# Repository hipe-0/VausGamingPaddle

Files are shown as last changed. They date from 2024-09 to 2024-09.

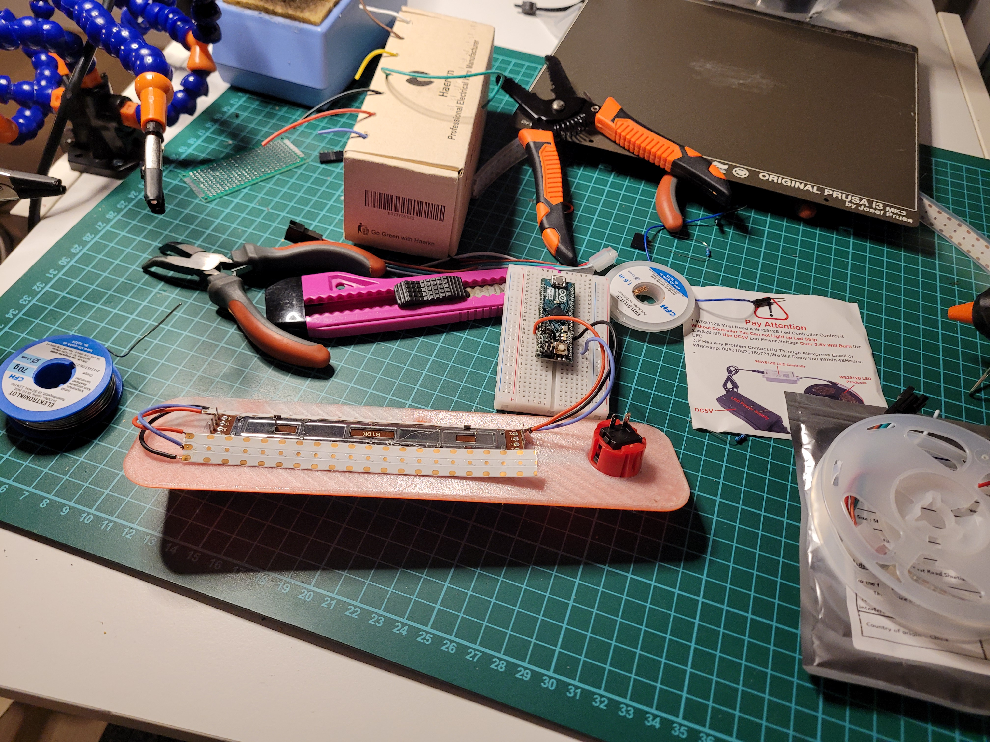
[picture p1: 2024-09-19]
20240102_201649.jpg

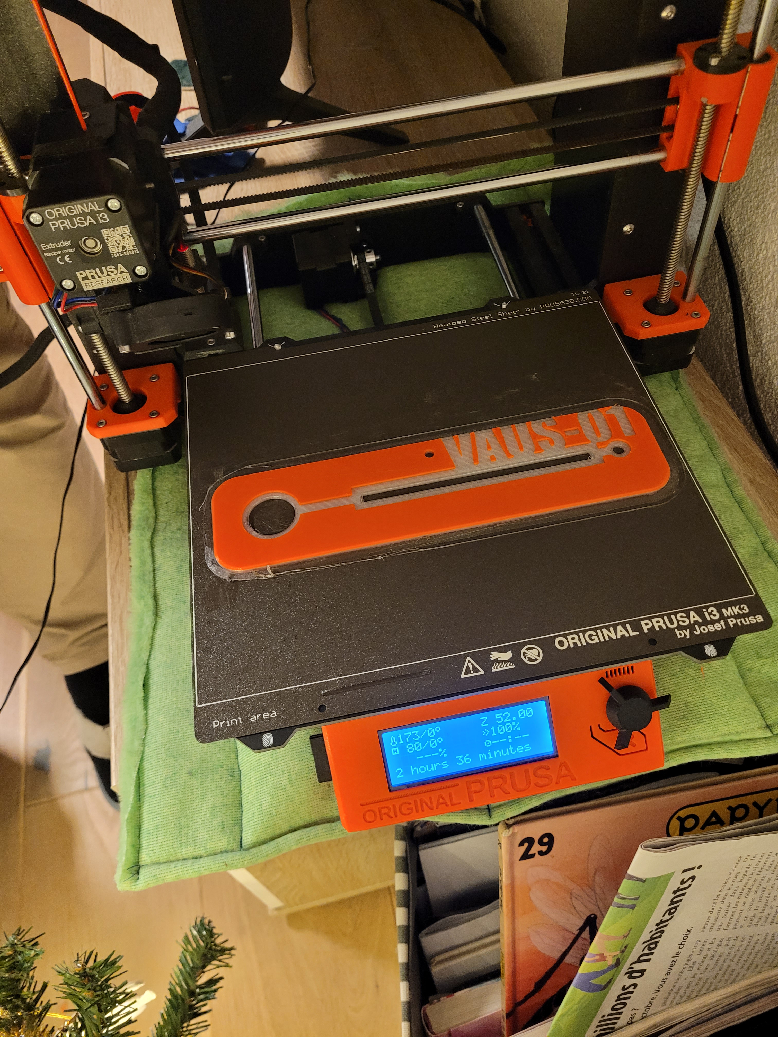
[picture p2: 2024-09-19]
20240102_172037.jpg

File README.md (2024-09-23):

# VausGamingPaddle

I created a 3D printed, open sourced, arduino based, "Arkanoid"-inspired game paddle for playing Arkanoid 1 or 2 games realistically.



https://github.com/user-attachments/assets/acdfcfb8-230b-40b3-95ee-57034bec4c22

Also works with other "breakout" inspired ball game that accept USB mouse as input.

Reference:
https://fr.wikipedia.org/wiki/Arkanoid

# Game controller description
- low, near zero latency
- USB A to usb Micro cable required
- compatibility with PC emulators or consoles
- The device emulates a mouse with only X direction
- 1 game button (for the Arkanoid game it is used as fire button)
- Main sensor bar is a large linear potentiometer, like the ones found on DJ mixer devices
- Paddle movements are accompanied by led effect when moving and firing
- Handles the left and right corners by moving the mouse faster
- Some mouse acceleration is added based on mouse speed, to improve reactivity
- Sensitivity can be changed by user using a potentiometer. Useful as screen resolution may differ from one game to the other.
- When idle for a few seconds, starts a beautiful led fireworks demo called "DemoReel100" by Fastled, found here: https://github.com/FastLED/FastLED/tree/master/examples/DemoReel100
- 3D printed model
- Main paddle element is shaped to resemble the Arkanoid 1 spaceship

https://github.com/user-attachments/assets/506902b2-bb77-4744-a214-cb1bdf7f73fd

# 3D models for 3D printing
3D model are available for free download on thingiverse
https://www.thingiverse.com/thing:6772436 

# Bill of Material:
- 1x Arduino micro (rev 3) 
- 1x WS2812B led strip cut to a length of 57 leds, density: 144 leds / meter
- 1x Smooth linear potentiometer 128mm 10K
- 1x 3D printed PETG body (dowload the files for free for 3D printing)
- 1x Mini rotational linear potentiometer 100K
- 1x Resistance 1K
- 1x led
- 1x capacitor 1uF 63v
- 1x arcade button switch diameter 24mm
- 1x prototype soldering board
- 1x USB cable, 2m, USB A male to micro USB male
- some cables to solder
- solder
- hot glue

# Shematic
2024-09-23 Vaus Gaming paddle shematic v1 02_bb
2024-09-23 Vaus Gaming paddle shematic v1 02_schéma

# PCB Printed Circuit board
Not tested yet, but you can try my new PCB design (file in repository) for this project (cost estimate: 18 Euros for 3 boards)
2024-09-23 Vaus Gaming paddle shematic v1 02_circuit imprimé

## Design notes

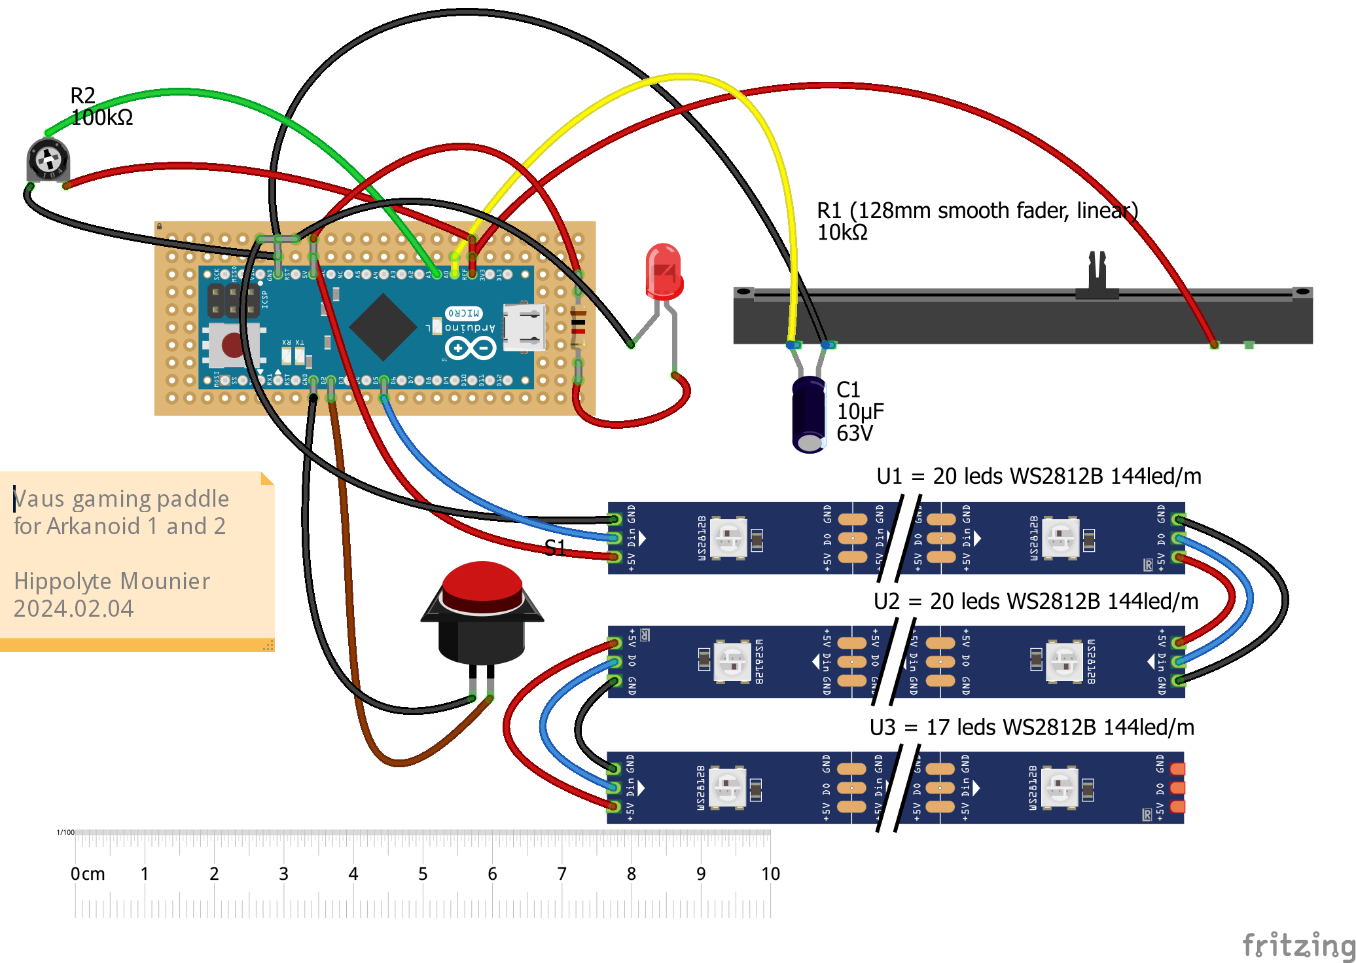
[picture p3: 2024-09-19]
2024-02-04 Vaus Gaming paddle shematic v0.01_bb.png

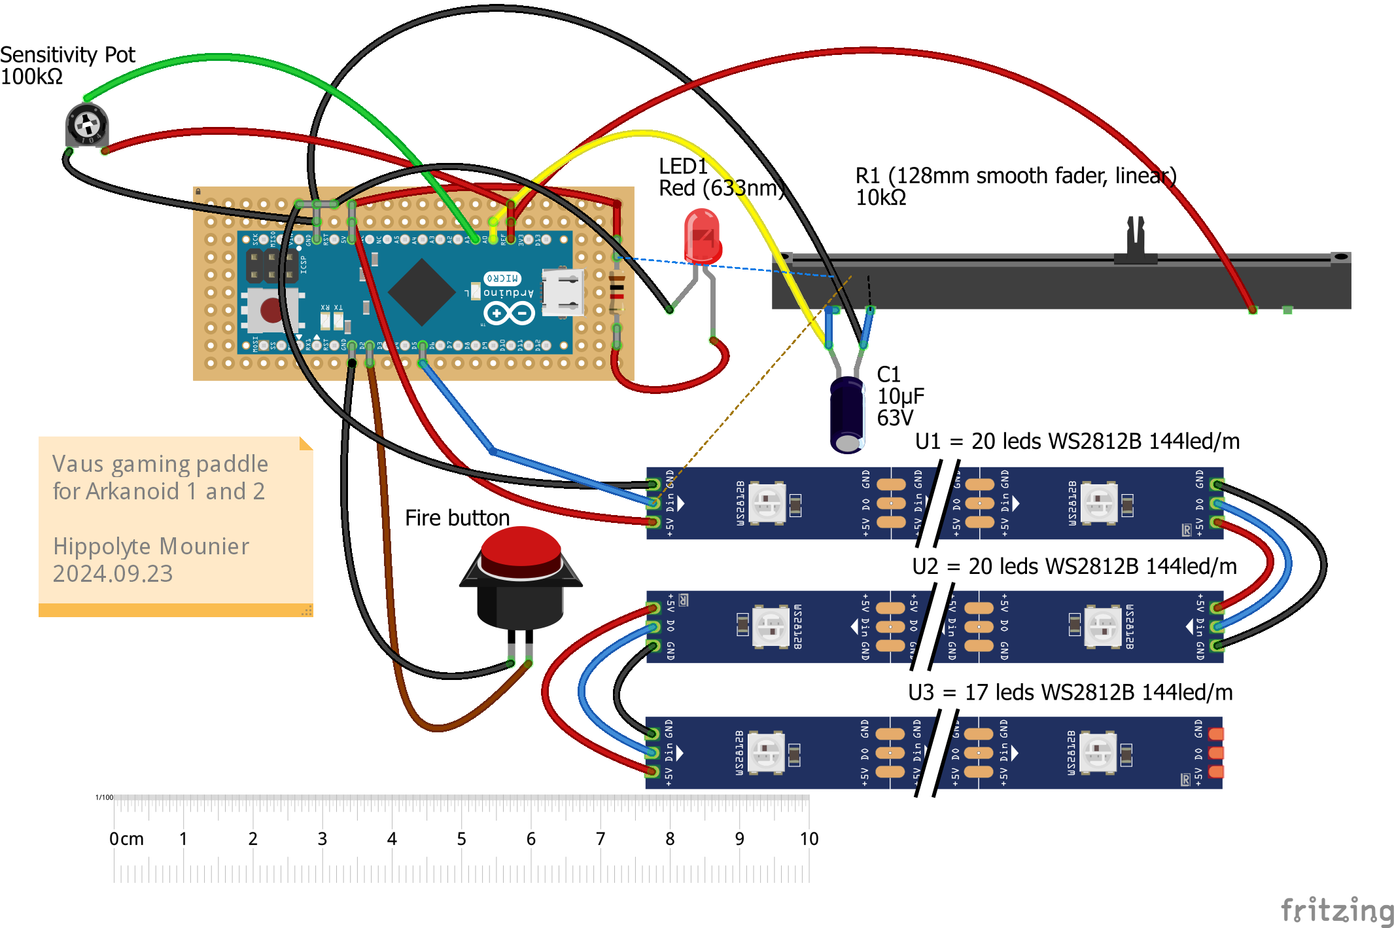
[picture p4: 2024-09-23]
shematic/2024-09-23 Vaus Gaming paddle shematic v1.02_bb.png

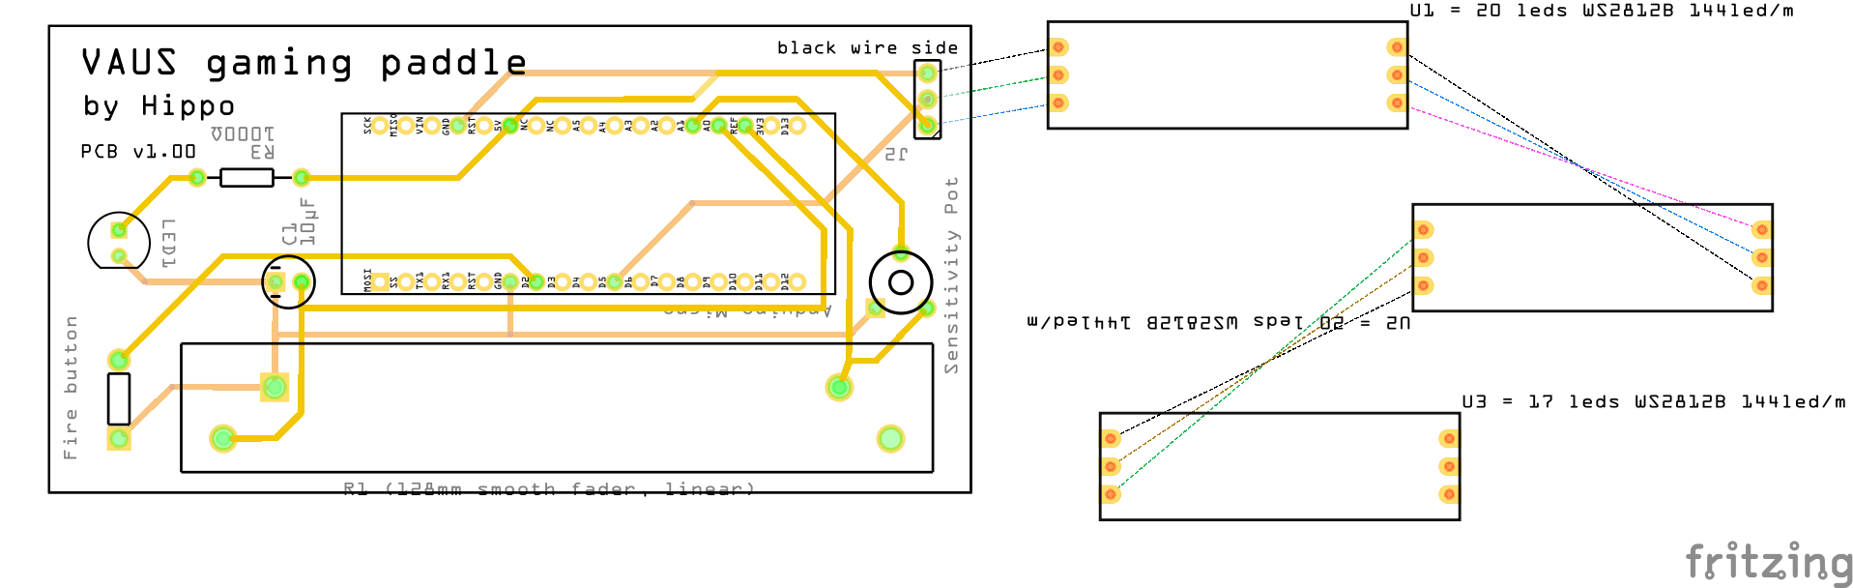
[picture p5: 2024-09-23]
Gerber/2024-09-23 Vaus Gaming paddle shematic v1.02_circuit imprimé.png

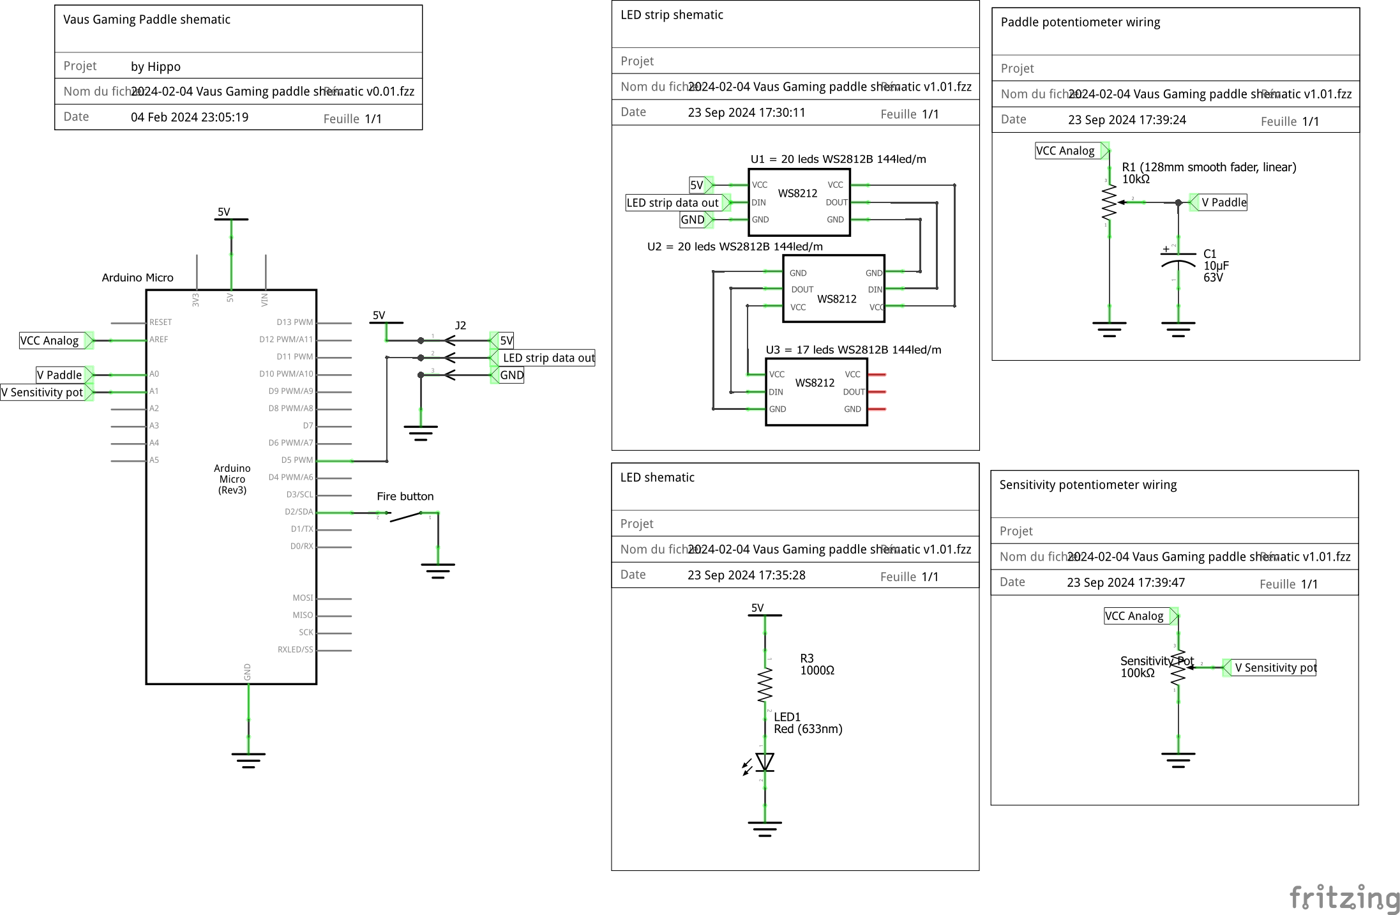
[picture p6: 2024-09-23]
shematic/2024-09-23 Vaus Gaming paddle shematic v1.02_schéma.png

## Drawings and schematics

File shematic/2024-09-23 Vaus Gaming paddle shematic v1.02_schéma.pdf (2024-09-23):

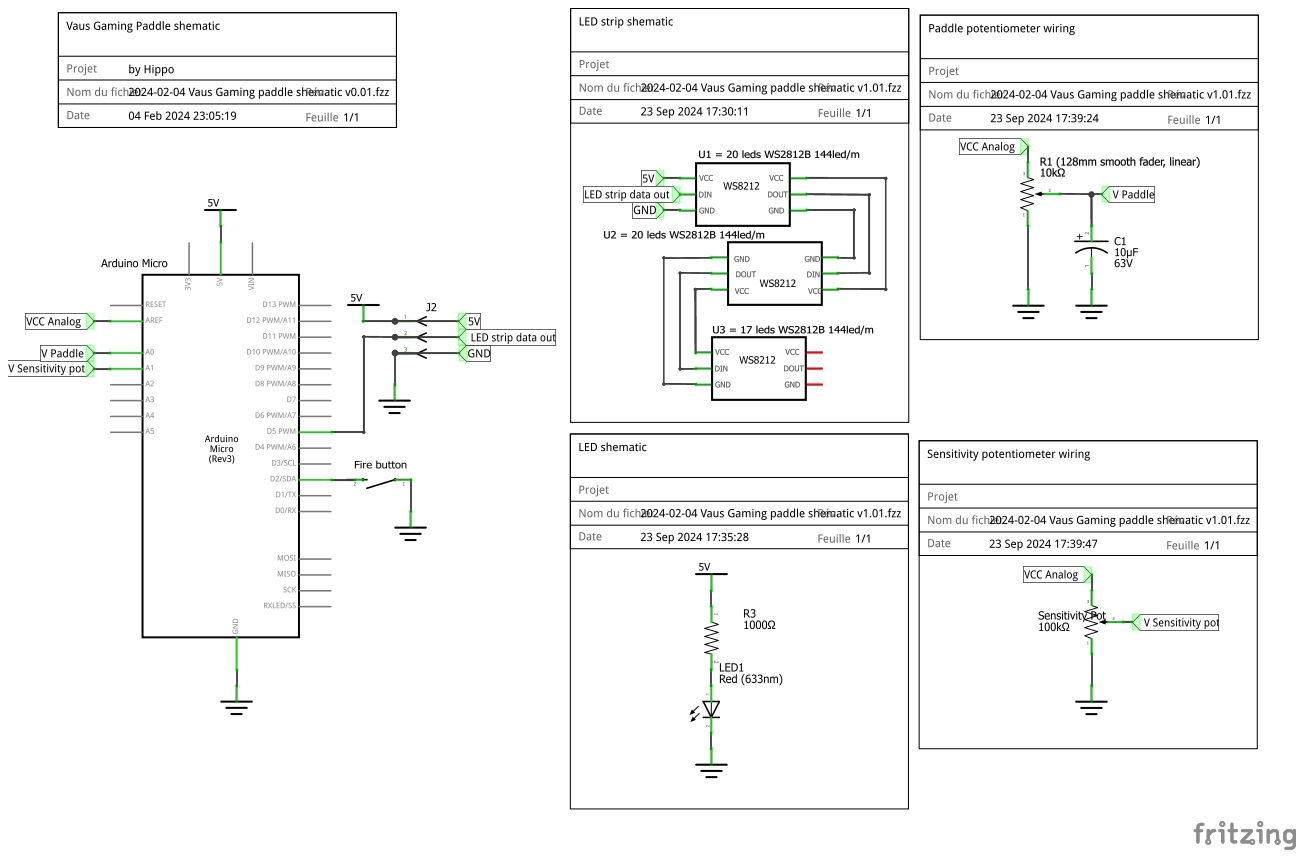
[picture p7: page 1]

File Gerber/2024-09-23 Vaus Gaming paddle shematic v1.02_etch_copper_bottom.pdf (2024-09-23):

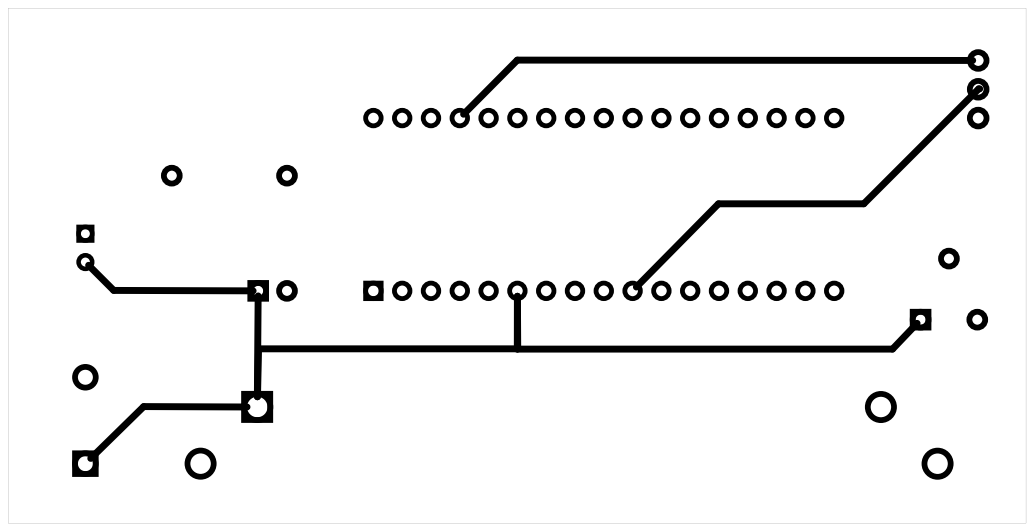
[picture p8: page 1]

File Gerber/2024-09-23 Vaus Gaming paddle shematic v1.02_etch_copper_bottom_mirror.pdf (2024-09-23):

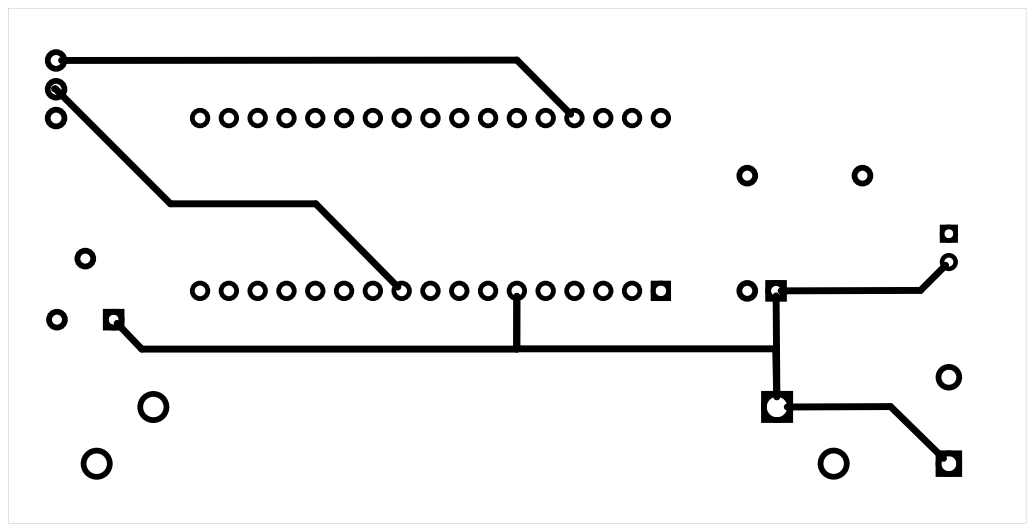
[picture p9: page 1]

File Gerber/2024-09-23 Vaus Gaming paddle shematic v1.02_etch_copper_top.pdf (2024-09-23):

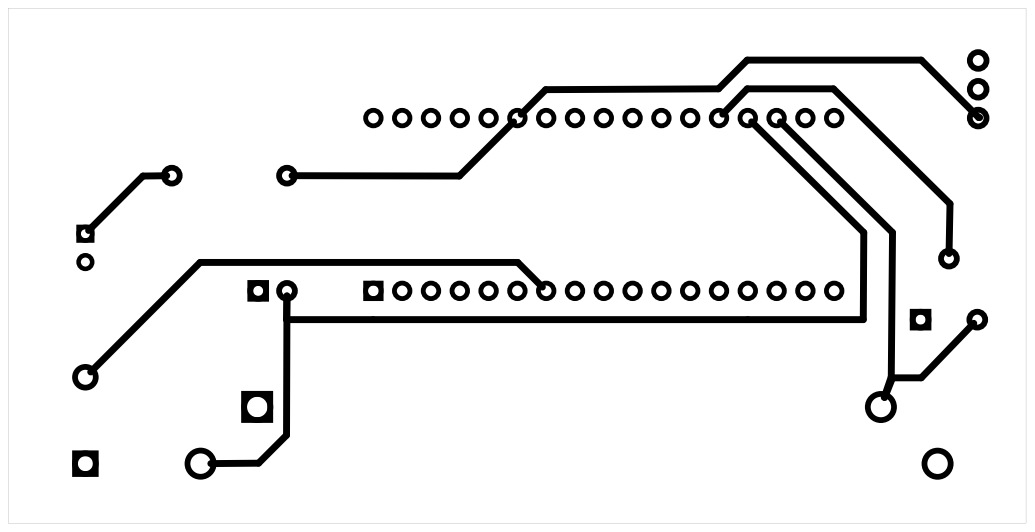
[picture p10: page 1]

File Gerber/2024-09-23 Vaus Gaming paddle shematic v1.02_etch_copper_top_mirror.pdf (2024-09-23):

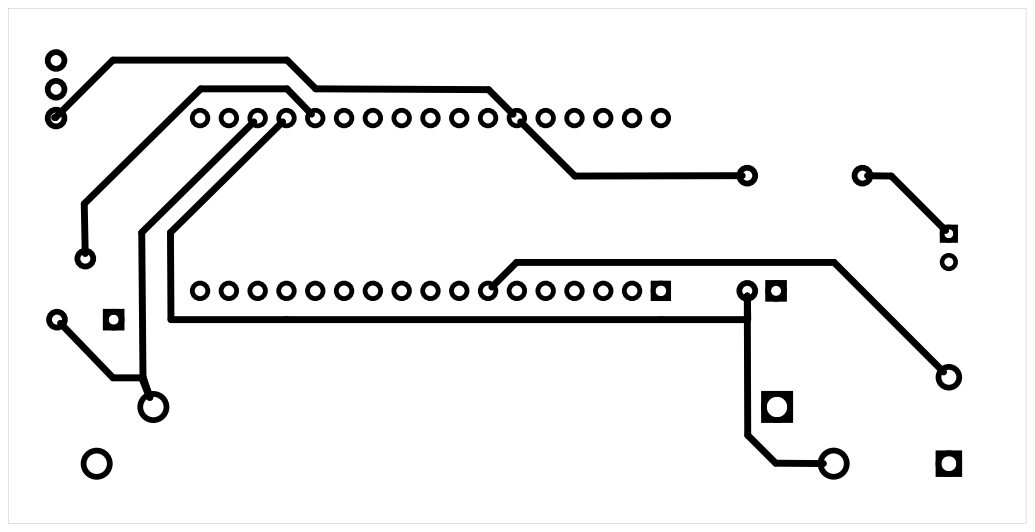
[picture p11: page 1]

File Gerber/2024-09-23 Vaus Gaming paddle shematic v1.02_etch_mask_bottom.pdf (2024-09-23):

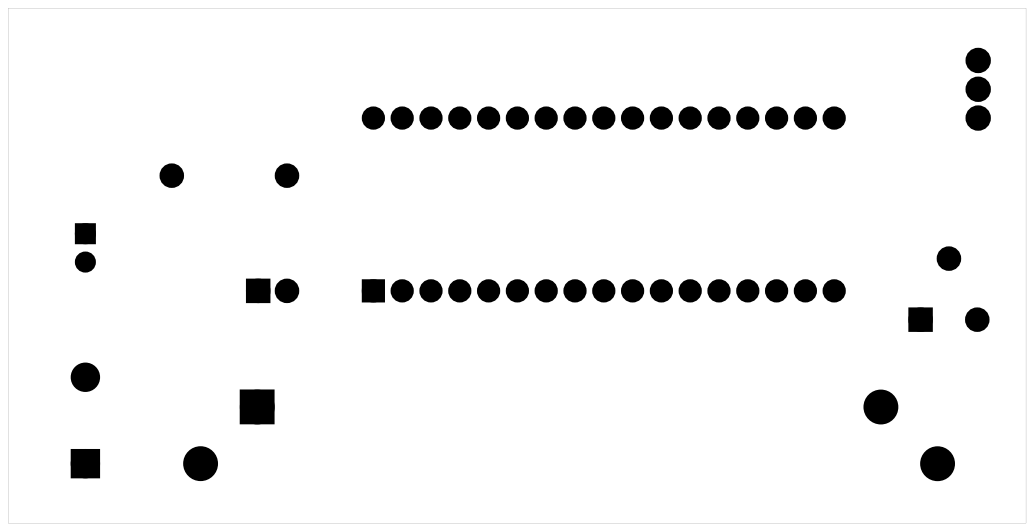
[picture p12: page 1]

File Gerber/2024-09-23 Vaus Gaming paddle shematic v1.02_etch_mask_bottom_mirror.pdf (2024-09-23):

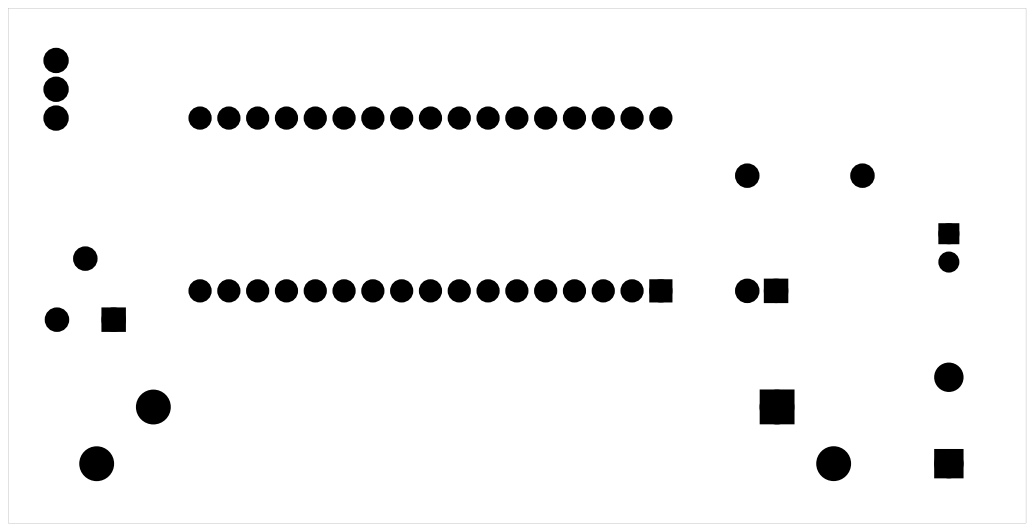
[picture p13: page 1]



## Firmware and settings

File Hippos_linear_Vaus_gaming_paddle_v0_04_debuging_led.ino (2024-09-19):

/* Linear game paddle to play Arkanoid
by Hippolyte Mounier
2024-01-05

*/
#define VERSION "Hippo Vaus Paddle v0.04"

#include "myleds.h"

#include <ezButton.h>
#include "Mouse.h"
#include "debug.h"
#include "PotFilter.h"

#define BUTTON_FIRE_PIN    2
#define X_POT_PIN         A0
#define SENSITIVITY_PIN   A1

#define DELAY_LIGHT_SHOW 10000 // 10 s
#define SENSITIVITY_LIGHT_SHOW 10
#define MOUSE_UPDATE_MILISECOND 5 // total 15 ms per loop = 66 Hz

PotFilter pot(X_POT_PIN);

ezButton ezbutton(BUTTON_FIRE_PIN);  // create ezButton object that attach to pin 4

long   lastmove       = 0;
float  sensitivity    = 1.0;
int    potValue2Last  = 0;

void setup() {
  Serial.begin(9600);
  DEBUGTXT(VERSION);

  Mouse.begin();
  ezbutton.setDebounceTime(50);  // set debounce time to 50 milliseconds

  ledinit();
  flash();
}

long loopTime=0;
int counter = 0;

void loop() 
{

  ezbutton.loop();  // MUST call the loop() function first
  if (ezbutton.isPressed())
  {
    Mouse.press(MOUSE_LEFT);
    DEBUGTXT("button pressed")
    fire();
    lastmove = millis();
  }

  if (ezbutton.isReleased())
  {
    Mouse.release(MOUSE_LEFT);
    DEBUGTXT("button released")
  }
  /*
  long time = millis();
  int deltaT = time-loopTime;
  loopTime = time;
  DEBUGVAL("delta time", deltaT)*/

  int mousex = pot.readDeltaInteger();
  
  Mouse.move(mousex , 0, 0);
  
  if (abs(mousex >= SENSITIVITY_LIGHT_SHOW)) 
  {
    DEBUGVAL2("Moving mousex", mousex, "rawDeltaX", pot.getRawDeltaX());
    lastmove = millis();
  }
  else
    DEBUGVAL2("       mousex", mousex, "rawDeltaX", pot.getRawDeltaX());


  if(millis() - lastmove > DELAY_LIGHT_SHOW) // 10 s
    ledloop();
  else
    ledPaddle(pot.getX());

  if (counter ++ > 20)
   {
    counter = 0;
    int potValue2 = analogRead(SENSITIVITY_PIN);
    sensitivity =  mapfloat(potValue2, 0, 1023, 0.3, 3)  ;
    if (abs(potValue2 - potValue2Last) > 10)
      DEBUGVAL("sensitivity", sensitivity);
    pot.setSensitivity(sensitivity);

    potValue2Last = potValue2;
  }

  delay(MOUSE_UPDATE_MILISECOND);

}

float mapfloat(float x, float in_min, float in_max, float out_min, float out_max)
{
  return  (x - in_min) * (out_max - out_min) / (float) (in_max - in_min) + out_min ;
}

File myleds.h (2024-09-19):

/// @file    DemoReel100.ino
/// @brief   FastLED "100 lines of code" demo reel, showing off some effects
/// @example DemoReel100.ino


#include <FastLED.h>
#include "debug.h"

FASTLED_USING_NAMESPACE

// FastLED "100-lines-of-code" demo reel, showing just a few 
// of the kinds of animation patterns you can quickly and easily 
// compose using FastLED.  
//
// This example also shows one easy way to define multiple 
// animations patterns and have them automatically rotate.
//
// -Mark Kriegsman, December 2014


#define DATA_PIN    4
//#define CLK_PIN   4
#define LED_TYPE    WS2812B
#define COLOR_ORDER GRB
#define NUM_LEDS    57
CRGB leds[NUM_LEDS];

#define BRIGHTNESS          96
#define FRAMES_PER_SECOND  120

void ledinit() { 
  // tell FastLED about the LED strip configuration
  FastLED.addLeds<LED_TYPE,DATA_PIN,COLOR_ORDER>(leds, NUM_LEDS).setCorrection(TypicalLEDStrip);
  //FastLED.addLeds<LED_TYPE,DATA_PIN,CLK_PIN,COLOR_ORDER>(leds, NUM_LEDS).setCorrection(TypicalLEDStrip);

  // set master brightness control
  FastLED.setBrightness(BRIGHTNESS);

  Serial.println("ledinit() finished");
}


// List of patterns to cycle through.  Each is defined as a separate function below.
typedef void (*SimplePatternList[])();

uint8_t gCurrentPatternNumber = 0; // Index number of which pattern is current
uint8_t gHue = 0; // rotating "base color" used by many of the patterns
 
#define ARRAY_SIZE(A) (sizeof(A) / sizeof((A)[0]))

void rainbow() 
{
  // FastLED's built-in rainbow generator
  fill_rainbow( leds, NUM_LEDS, gHue, 7);
}


void addGlitter( fract8 chanceOfGlitter) 
{
  if( random8() < chanceOfGlitter) {
    leds[ random16(NUM_LEDS) ] += CRGB::White;
  }
}

void rainbowWithGlitter() 
{
  // built-in FastLED rainbow, plus some random sparkly glitter
  rainbow();
  addGlitter(80);
}

void confetti() 
{
  // random colored speckles that blink in and fade smoothly
  fadeToBlackBy( leds, NUM_LEDS, 10);
  int pos = random16(NUM_LEDS);
  leds[pos] += CHSV( gHue + random8(64), 200, 255);
}

void sinelon()
{
  // a colored dot sweeping back and forth, with fading trails
  fadeToBlackBy( leds, NUM_LEDS, 20);
  int pos = beatsin16( 13, 0, NUM_LEDS-1 );
  leds[pos] += CHSV( gHue, 255, 192);
}

void bpm()
{
  // colored stripes pulsing at a defined Beats-Per-Minute (BPM)
  uint8_t BeatsPerMinute = 62;
  CRGBPalette16 palette = PartyColors_p;
  uint8_t beat = beatsin8( BeatsPerMinute, 64, 255);
  for( int i = 0; i < NUM_LEDS; i++) { //9948
    leds[i] = ColorFromPalette(palette, gHue+(i*2), beat-gHue+(i*10));
  }
}

void juggle() {
  // eight colored dots, weaving in and out of sync with each other
  fadeToBlackBy( leds, NUM_LEDS, 20);
  uint8_t dothue = 0;
  for( int i = 0; i < 8; i++) {
    leds[beatsin16( i+7, 0, NUM_LEDS-1 )] |= CHSV(dothue, 200, 255);
    dothue += 32;
  }
}

SimplePatternList gPatterns = { confetti, sinelon, juggle, bpm, rainbow, rainbowWithGlitter };


void nextPattern()
{
  // add one to the current pattern number, and wrap around at the end
  gCurrentPatternNumber = (gCurrentPatternNumber + 1) % ARRAY_SIZE( gPatterns);
}


void ledloop()
{
  // Call the current pattern function once, updating the 'leds' array
  gPatterns[gCurrentPatternNumber]();

  // send the 'leds' array out to the actual LED strip
  FastLED.show();  
  // insert a delay to keep the framerate modest
  FastLED.delay(1000/FRAMES_PER_SECOND); 

  // do some periodic updates
  EVERY_N_MILLISECONDS( 20 ) { gHue++; } // slowly cycle the "base color" through the rainbow
  EVERY_N_SECONDS( 10 ) { nextPattern(); } // change patterns periodically
}


void ledPaddle(int value)
{

  fadeToBlackBy( leds, NUM_LEDS, 20);
  int pos = (value*20)/1024;
  //DEBUGVAL("pos", pos)
  leds[pos] += CHSV( gHue, 255, 192);
  leds[39-pos] += CHSV( gHue, 255, 192);
    // send the 'leds' array out to the actual LED strip

  FastLED.show();  
  // insert a delay to keep the framerate modest
  FastLED.delay(1000/FRAMES_PER_SECOND); 

  // do some periodic updates
  EVERY_N_MILLISECONDS( 20 ) { gHue++; } // slowly cycle the "base color" through the rainbow
  EVERY_N_SECONDS( 10 ) { nextPattern(); } // change patterns periodically
}

void fire()
{
  for (int i = 40; i<NUM_LEDS; i++)
    leds[i] += CHSV( gHue, 255, 192);
}

void flash()
{
  for (int i = 0; i<NUM_LEDS; i++)
    leds[i] = CHSV( 0, 0, 255);
}
